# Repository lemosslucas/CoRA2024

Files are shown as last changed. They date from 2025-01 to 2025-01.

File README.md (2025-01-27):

# CoRA 2024 (Competição de Robôs Autônomos) - Line Follower

CoRA2024 Banner

This is a repository containing all the files utilised on the development and tests of our autonomous line follower robot.
The competition challenge participants to prototype, build, program and test the robot from scratch, with the help of tools such as Arduino (and languages alike), and CAD and Simulation softwares.

## File Structure
- `data/`: All the relevant data acquired during testing and programs to do so
- `miscellaneous`: All the files regarding the building of the robot and circuitry
- `CoRA2024.ino`: Main file in Arduino to compile/run the code and test the robot
- `motores.cpp`: Specific script to implement the motorised functions of the robot
- `motores.h`: Library referring to `motores.cpp` and its functions
- `desafios.cpp`: Specific scripts to tackle the track's challenges with the robot 
- `desafios.h`: Library referring to `desafios.cpp` and its functions

## Technologies used
### Programming Languages
- [Arduino / C++](https://www.arduino.cc/): Main Framework
- [C](https://learn.microsoft.com/pt-br/cpp/c-language/): Libraries and other implementations
- [Python](https://python.org): Data Analysis
- [MATLAB](https://www.mathworks.com/products/matlab.html): Data Plotting and Analysis

### Hardware
<a href="miscellaneous/CoRA2024_ElectronicCircuit.png">
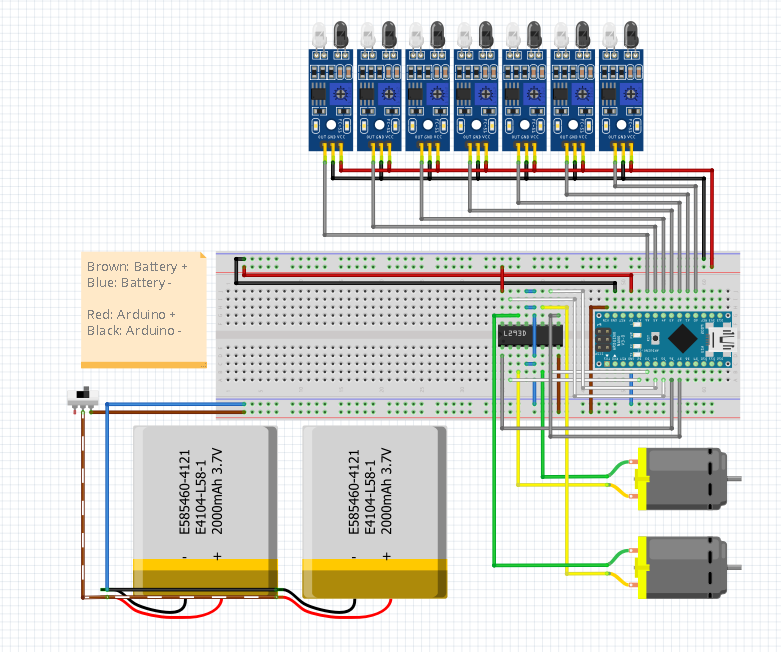
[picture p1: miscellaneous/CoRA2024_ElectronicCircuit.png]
Electronic Circuit
  
</a>
<p><b>This is a schematic of the electronic circuitry used.</b></p>

- [2x Yellow DC Motors](https://i0.wp.com/myduino.com/wp-content/uploads/2023/09/2-40.jpg?w=600&ssl=1) - **Specs:** 3V-12VDC; 1:48 gear ratio; 800g/cm max. @ 3VDC; 70mA (250mA max. @ 3VDC)
- [2x Yellow DC Motor Wheels](https://kitsguru.com/cdn/shop/products/tracked-wheel-for-bo-motor-yellow-26mm-width_2048x.jpg?v=1642829900)
- [1x Swivel Caster Wheel](https://www.institutodigital.com.br/wp-content/uploads/2020/10/rodizio-giratorio-25mm-2.png)
- [2x 18650 Lithium-ion battery cells](https://electrostoreshop.com/wp-content/uploads/2024/04/3-7v-2000mah-18650-rechargeable-li-ion-lithium-battery.jpg) - **Specs:** 3.7VDC; 2000mAh
- [1x Arduino Nano](https://store.arduino.cc/products/arduino-nano)
- [1x Breadboard and Jumper Cables](https://images.squarespace-cdn.com/content/v1/556646a4e4b0bda793faf918/1595041751201-D74U6ZYRW93A6ZW6YYMK/BRBRD830J+Breadboard+MB102+w.+65+Jumper+cables.jpg)
- [1x L293D CI Motor Driver](https://www.ti.com/lit/ds/symlink/l293.pdf?HQS=dis-mous-null-mousermode-dsf-pf-null-wwe&ts=1723753701665)
- [7x TCRT5000 Infrared Sensors](https://www.haoyuelectronics.com/Attachment/TCRT5000/tcrt5000.pdf)

## Media and Miscellaneous
<a href="https://www.youtube.com/watch?v=5h6ZvlgcDps">
  Participation in the Autonomous Robot Competition at UFMG (CoRA) 2024
</a>
<p>This video showcases our participation in the Autonomous Robot Competition at UFMG (CoRA) 2024, and our performance in the Final round.</p>

<a href="miscellaneous/CoRA2024_LaserCutChassis.png">
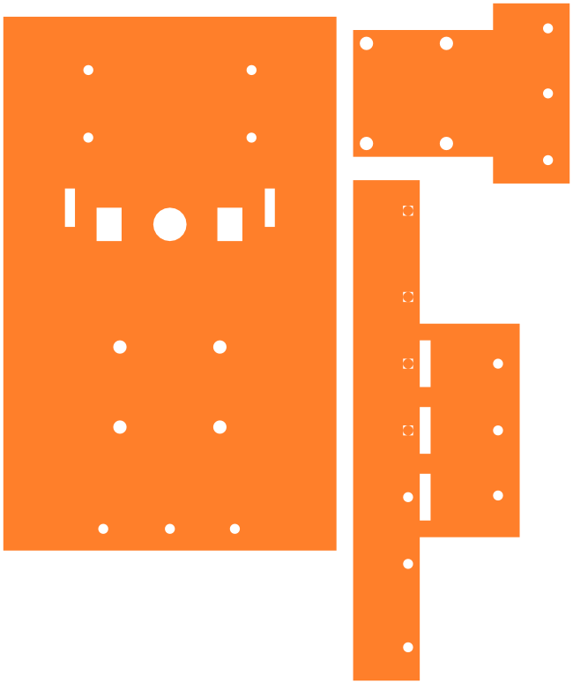
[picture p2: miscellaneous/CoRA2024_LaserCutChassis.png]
Laser Cut Chassis
  
</a>
<p>This is the vector of the chassis used to assemble the parts on, and thus the whole robot.</p>

<a href="miscellaneous/CoRA2024_SharkFrame3DPrinting.png">
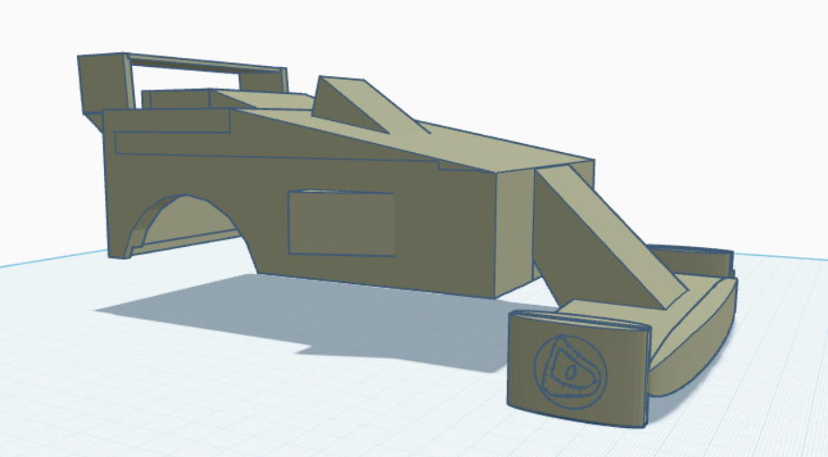
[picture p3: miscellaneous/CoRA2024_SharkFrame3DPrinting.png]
Shark Frame 3D Printing
  
</a>
<p>This is the representation of our decorative frame for the robot.</p>

## Developers

<table>
  <tr>
    <td align="center" style="max-width: 200px;">
      <a href="https://github.com/lemosslucas" target="_blank">
        
      </a>
      <br/>
      <a href="https://github.com/lemosslucas"><strong>Lucas Lemos Ricaldoni</strong></a><br/>
      <span>Lead Programmer, Principal Technician</span>
    </td>
    <td align="center" style="max-width: 200px;">
      <a href="https://github.com/mateusdcp13"> 
        
      </a>
      <br/>
      <a href="https://github.com/mateusdcp13"><strong>Mateus de Carvalho Pedrosa</strong></a><br/>
      <span>Lead Prototyper and Technician</span>
    </td>
    <td align="center" style="max-width: 200px;">
      <a href="https://github.com/PauloMendesPVRM"> 
        
      </a>
      <br/>
      <a href="https://github.com/PauloMendesPVRM"><strong>Paulo Vasconcelos Mendes</strong></a><br/>
      <span>Lead Designer and Support Prototyper</span>
    </td>
  </tr>
</table>

### Name of the team: "Pregadores"

## License
This project is licensed under the MIT License. See the file [LICENSE](LICENSE) for details.

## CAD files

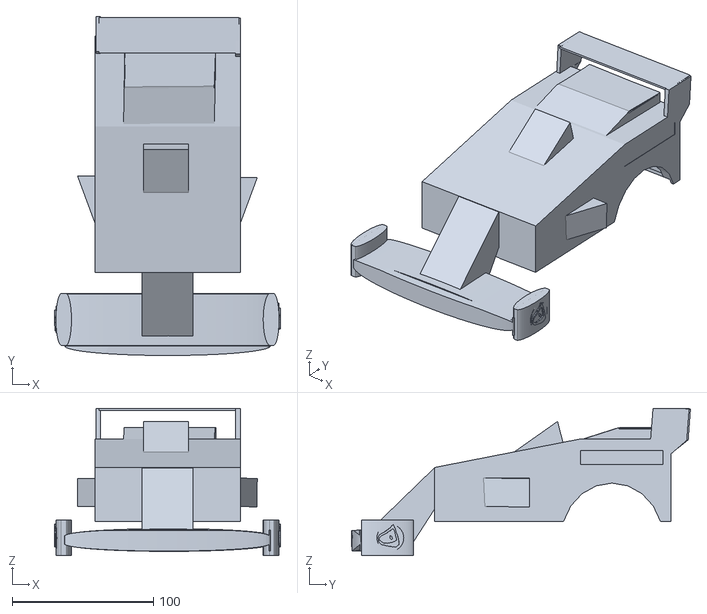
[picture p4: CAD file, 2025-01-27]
miscellaneous/CoRA2024_SharkFrame3DPrinting.stl
160.0 x 240.0 x 104.3

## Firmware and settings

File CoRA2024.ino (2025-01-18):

#include "motores.h"
#include "desafios.h"

// define os sensores
// sensor1_A1 == ESQUERDA :: sensor5_A5 == DIREITA // sensor0_curva_A0 == ESQUERDA & sensor6_curva_A6 == DIREITA
const int sensor1_A1 = 15;
const int sensor2_A2 = 16;
const int sensor3_A3 = 17;
const int sensor4_A4 = 18;
const int sensor5_A5 = 19;

//sensores para a curva
const int sensor0_curva_A0 = 14;
const int sensor6_curva_A6 = 10;

// variaveis para ler a saida do sensor
int SENSOR[5];
int SENSOR_CURVA[2];

#define BRANCO 0
#define PRETO 1
#define OFFSET 0
#define LINHA_NAO_DETECTADA -5
#define QUANTIDADE_TOTAL_SENSORES 5
#define CURVA_NAO_ENCONTRADA 0

#define DETECCAO_POR_QUADRADO 1
#define SAIDA_ESQUERDA 0
#define SAIDA_DIREITA 1
int saida_rotatoria = -1;

const int velocidadeBaseDireita = 160; 
const int velocidadeBaseEsquerda = 180; 
int velocidadeDireita = 0;
int velocidadeEsquerda = 0;

// variaveis para o calculo do PID
float erro = 0;
float erroAnterior = 0;
float I = 0, P = erro, D = 0, PID = 0;

//Constante para a utilizacao do metodo Ultimate Gain
const float Kcr = 150, Pcr = 0.05;

//parece que o melhor Kp é [150]
//const float Kp = 150, Ki = 0, Kd = 0;
const float Kp = (0.6 * Kcr), Ki = ((2 * Kp) / Pcr), Kd = ((Kp * Pcr) / 8);

// variavel para deteccao da faixa de pedestre
bool faixa_de_pedestre = false;

void setup() {
  // inicializacao dos sensores
  pinMode(sensor1_A1, INPUT);
  pinMode(sensor2_A2, INPUT);
  pinMode(sensor3_A3, INPUT);
  pinMode(sensor4_A4, INPUT);
  pinMode(sensor5_A5, INPUT);
  pinMode(sensor0_curva_A0, INPUT);
  pinMode(sensor6_curva_A6, INPUT);

  // garante que o carro começe parado
  parar();
  delay(2000);

  // inicializa a comunicacao serial
  Serial.begin(9600);
}

/**
 * @brief Le os estados [0, 1] detectados pelo sensor.
 * 
 * Atualiza os arrays SENSOR & SENSOR_CURVA com os valores
 * atuais detectados pelo sensor
 */
void ler_sensores() {
  SENSOR[0] = digitalRead(sensor1_A1);
  SENSOR[1] = digitalRead(sensor2_A2);
  SENSOR[2] = digitalRead(sensor3_A3);
  SENSOR[3] = digitalRead(sensor4_A4);
  SENSOR[4] = digitalRead(sensor5_A5);

  SENSOR_CURVA[0] = digitalRead(sensor0_curva_A0);
  SENSOR_CURVA[1] = digitalRead(sensor6_curva_A6);
}

/**
 * @brief Ajusta o movimento do carro
 * 
 * Apartir do valor gerado pelo PID junto com a velocidade base dos motores
 * altera a direção do movimento para permanecer na linha
 */
void ajusta_movimento() {
  // altera o valor de velocidade
  velocidadeDireita = constrain(velocidadeBaseDireita - PID, 0, 255);
  velocidadeEsquerda = constrain(velocidadeBaseEsquerda + PID, 0, 255);
  
  // envia a nova velocidade para a função andar
  andar(velocidadeDireita, velocidadeEsquerda);
}

/**
 * @brief Calcula o erro do carro em relação a linha
 * 
 * Realiza uma media ponderada com os valores do sensor
 * gerando o erro do carro em relacao a linha.
 */
void calcula_erro() {
  // atualiza os valores do sensor
  ler_sensores();

  // verifica se houve inversao, sinalizando uma faixa de pedestre
  if (verifica_inversao(SENSOR, SENSOR_CURVA)) {
    faixa_de_pedestre = true;
  }

  // inicializa as variaveis para o calculo do erro
  int pesos[5] = {-2, -1, 0, 1, 2};
  int somatorioErro = 0;
  int sensoresAtivos = 0;

  // realiza um somatorio com os valores e o peso dos sensores
  for (int i = 0; i < 5; i++) {
    somatorioErro += SENSOR[i] * pesos[i];
    sensoresAtivos += SENSOR[i];
  }

  // determina o erro do carro
  if (sensoresAtivos == QUANTIDADE_TOTAL_SENSORES) {
    erro = LINHA_NAO_DETECTADA;
  } else {
    int sensoresInativos = QUANTIDADE_TOTAL_SENSORES - sensoresAtivos;
    erro = somatorioErro / sensoresInativos;
  }
}

/**
 * @brief Realiza o calculo do PID
 * 
 * A partir do erro e os valores das constantes,
 * Kp, Ki e Kd predefinidas realiza o calculo do
 * Controle Proporcional Derivativo (PID)
 */
void calcula_PID() {
  // inicializa as variaveis para o calculo
  PID = 0;
  P = erro;
  I = constrain(I + P, -255, 255);
  D = erro - erroAnterior;

  // calcula o PID
  PID = (Kp * P) + (Ki * I) + (Kd * D) + OFFSET;

  // atualiza o valor do PID
  erroAnterior = erro;
}

/**
 * @brief Imprime os dados do carro no monitor serial
 * 
 * Imprime os valores lido, PID, erro e a velocidade do carro
 */
void imprime_serial() {
  // imprime os valores do sensores
  Serial.print(SENSOR_CURVA[0]);
  Serial.print(" | ");

  for (int i = 0; i < 5; i++) {
    Serial.print(SENSOR[i]);
    Serial.print(" | ");
  }

  Serial.print(SENSOR_CURVA[1]);
  Serial.print(" | ");

  // imprime as variaveis Erro, PID, e velocidades
  Serial.print("\tErro: ");
  Serial.print(erro);
  Serial.print(" PID: ");
  Serial.print(PID);
  Serial.print(" Velocidade Direita: ");
  Serial.print(velocidadeDireita);
  Serial.print(" Velocidade Esquerda: ");
  Serial.println(velocidadeEsquerda);
}

/**
 * @brief Determina o lado da saída em uma rotatória baseado no número de marcações detectadas.
 * 
 * @param marcacoesEsquerda Armazena as marcacoes a esquerda
 * @param marcacoesDireita Armazena as marcacoes a direita
 * 
 * A partir do numero de marcações a função atualiza o lado correto para
 * a saida do carro na rotatoria.
 * 
 * @return int saidaDesejada 
 */
int determina_saida_rotatoria(int marcacoesEsquerda, int marcacoesDireita) {
  // inicializa com 0 a variavel
  int saidaDesejada = 0;

  // verifica qual lado deve ser feito a saida
  if (marcacoesEsquerda > marcacoesDireita) {
    // calcula a saida apartir do numero de marcacaoes por detecacao no intervalo de tempo + OFFSET(1)
    saidaDesejada = (marcacoesEsquerda / DETECCAO_POR_QUADRADO) + 1;
    // realiza o movimento para entrar na rotatoria
    curva_esquerda(velocidadeBaseDireita, velocidadeBaseEsquerda);
    // atualiza o valor da saida
    saida_rotatoria = SAIDA_ESQUERDA;
  } else if(marcacoesEsquerda < marcacoesDireita) {
    // calcula a saida apartir do numero de marcacaoes por detecacao no intervalo de tempo + OFFSET(1)
    saidaDesejada = (marcacoesDireita / DETECCAO_POR_QUADRADO) + 1; 
    // realiza o movimento para entrar na rotatoria
    curva_direita(velocidadeBaseDireita, velocidadeBaseEsquerda);
    // atualiza o valor da saida
    saida_rotatoria = SAIDA_DIREITA;
  }
  
  //retorna o valor de saida
  return saidaDesejada;
}

/**
 * @brief Realiza a saida na rotatoria
 * 
 * @param saidaDesejada Numero que deve ser feito a saida da rotatoria
 * 
 * O carro segue o percurso ate chegar na `saidaDesejada`
 */
void realiza_rotatoria(int saidaDesejada){
  // inicializa a saida atual
  int saidaAtual = 1;

  // loop para que o carro sai apenas na saida correta
  while(saidaAtual != saidaDesejada) {
    // calcula o erro para manter o carro na linha
    calcula_erro();
    ajusta_movimento();

    // verifica qual lado deve ser feito a saida
    if (saida_rotatoria == SAIDA_ESQUERDA) {
      // verifica se ha alguma marcacao na direita
      if (calcula_sensores_ativos(SENSOR) <= 3 && SENSOR_CURVA[0] == PRETO && SENSOR_CURVA[1] == BRANCO) {
        delay(200);
        // atualiza o valor da saida atual
        saidaAtual++;
      }
    } else if(saida_rotatoria == SAIDA_DIREITA) {
      // verifica se ha alguma marcacao na esquerda
      if (calcula_sensores_ativos(SENSOR) <= 3 && SENSOR_CURVA[0] == BRANCO && SENSOR_CURVA[1] == PRETO) {
        delay(200);
        // atualiza o valor da saida atual
        saidaAtual++;
      }
    }
  }
  
  // sai para o lado correto da rotatoria
  if (saida_rotatoria == SAIDA_ESQUERDA) {
    curva_esquerda(velocidadeBaseDireita, velocidadeBaseEsquerda);
  } else {
    curva_direita(velocidadeBaseDireita, velocidadeBaseEsquerda);
  }
}

/**
 * @brief Realiza a marcha re
 * 
 * @param int historico
 * 
 * A partir do historico o robo segue o trajeto dando marcha re e
 * ao chegar ao determinado local ele vira para o lado indicado
 */
void realiza_marcha_re(int historico[]) {
  // atualiza o valor de historico
  for (int i = 0; i < DETECCAO_POR_QUADRADO; i++) {
    if (i > 0) {
      historico[i] == historico[i - 1];
    } 
  }

  // realiza a re ate chegar no local maximo
  while (erro != LINHA_NAO_DETECTADA) {
    andar_de_re(255, 255);
    calcula_erro();
  }
  parar();
  delay(500);

  // se o primeiro for esquerda ele vira a direita
  if (historico[1] == SAIDA_ESQUERDA) {
    curva_direita(velocidadeBaseDireita, velocidadeBaseEsquerda);
  } else {
    curva_esquerda(velocidadeBaseDireita, velocidadeBaseEsquerda);
  }
}

void loop() {
  // iniciliza as variaveis
  int marcacoesDireita = 0, marcacoesEsquerda = 0;
  // calcula o erro do carro sobre a linha
  calcula_erro();

  // verifica se ha uma curva de 90
  int saidaCurva = verifica_curva_90(SENSOR, SENSOR_CURVA);
  int historico_curva[4 * DETECCAO_POR_QUADRADO];
  int i = 0;

  // verifica se a curva foi detectada
  if (saidaCurva != CURVA_NAO_ENCONTRADA) { 
    // caso tenha curva armazena a quantidade de marcaçoes
    while(erro != LINHA_NAO_DETECTADA) {
      // atualiza o valor dos sensores
      ler_sensores();
      
      // atualiza os valores de identificacao
      if (SENSOR_CURVA[0] == BRANCO) {
        marcacoesEsquerda++;
        historico_curva[i] = SAIDA_ESQUERDA;
      } else if (SENSOR_CURVA[1] == BRANCO) {
        marcacoesDireita++;
        historico_curva[i] = SAIDA_DIREITA;
      }

      i++;
      // garantem que o robo continue na linha
      calcula_erro();
      calcula_PID();
      ajusta_movimento();
    }
    
    // determina qual acao deve ser feita
    if (marcacoesEsquerda == DETECCAO_POR_QUADRADO || marcacoesDireita == DETECCAO_POR_QUADRADO) {
      realiza_curva_90(saidaCurva);
    } else if ((marcacoesEsquerda / DETECCAO_POR_QUADRADO) > 1 && (marcacoesDireita / DETECCAO_POR_QUADRADO) > 1) {
      realiza_marcha_re(historico_curva);
    } else{
      determina_saida_rotatoria(marcacoesEsquerda, marcacoesDireita);
    }

    parar();
  } else {
    // caso nao detectado curva e tenha perdido a linha
    if (erro == LINHA_NAO_DETECTADA) {
      // atualiza o numero de sensores ativos
      int sensoresAtivos = calcula_sensores_ativos(SENSOR);
      PID = 0;
      parar();

      // verifica se é uma faixa de pedestre
      if (faixa_de_pedestre == true) {
        realiza_faixa_de_pedestre();
        faixa_de_pedestre = false;
      } else {  
        delay(10000);

        // realiza uma re ate que volte para a linha
        while(sensoresAtivos == QUANTIDADE_TOTAL_SENSORES) {
          ler_sensores();
          sensoresAtivos = calcula_sensores_ativos(SENSOR);
          andar_de_re(255, 255);
        }

        parar();
      }

    } else {
      // caso o carro detecte a linha ele segue a linha
      calcula_PID();
      ajusta_movimento();
    }
  }

  // obtem a saida dos dados do carro
  imprime_serial(); 
  delay(5);
}

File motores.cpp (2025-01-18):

#include "motores.h"

// define a porta dos motores
const int MOTOR_ESQUERDO_HORARIO = 3;
const int MOTOR_ESQUERDO_ANTI = 4;
const int MOTOR_DIREITO_HORARIO = 7;
const int MOTOR_DIREITO_ANTI = 8;

const int MOTOR_PWM_ESQUERDO = 5;
const int MOTOR_PWM_DIREITO = 6;

void setup_motor() {
  pinMode(MOTOR_ESQUERDO_HORARIO, OUTPUT);
  pinMode(MOTOR_ESQUERDO_ANTI, OUTPUT);
  pinMode(MOTOR_DIREITO_HORARIO, OUTPUT);
  pinMode(MOTOR_DIREITO_ANTI, OUTPUT);

  pinMode(MOTOR_PWM_ESQUERDO, OUTPUT);
  pinMode(MOTOR_PWM_DIREITO, OUTPUT);
}

/**
 * @brief Move o veiculo para frente com as velocidades especificadas.
 * 
 * Configura os motores para se moverem para frente e ajusta suas velocidades
 * individualmente usando PWM.
 * 
 * @param velocidadeDireita Velocidade do motor direito (0 a 255).
 * @param velocidadeEsquerda Velocidade do motor esquerdo (0 a 255).
 */
void andar(int velocidadeDireita, int velocidadeEsquerda) {
  digitalWrite(MOTOR_ESQUERDO_ANTI, LOW);
  digitalWrite(MOTOR_ESQUERDO_HORARIO, HIGH);
  digitalWrite(MOTOR_DIREITO_HORARIO, HIGH);
  digitalWrite(MOTOR_DIREITO_ANTI, LOW);

  analogWrite(MOTOR_PWM_ESQUERDO, velocidadeEsquerda);
  analogWrite(MOTOR_PWM_DIREITO, velocidadeDireita);
}

/**
 * @brief Para todos os motores, interrompendo o movimento do veiculo.
 */
void parar() {
  digitalWrite(MOTOR_ESQUERDO_ANTI, LOW);
  digitalWrite(MOTOR_ESQUERDO_HORARIO, LOW);
  digitalWrite(MOTOR_DIREITO_HORARIO, LOW);
  digitalWrite(MOTOR_DIREITO_ANTI, LOW);
}

/**
 * @brief Move o veiculo para tras com as velocidades especificadas.
 * 
 * Configura os motores para se moverem para tras e ajusta suas velocidades
 * individualmente usando PWM.
 * 
 * @param velocidadeDireita Velocidade do motor direito (0 a 255).
 * @param velocidadeEsquerda Velocidade do motor esquerdo (0 a 255).
 */
void andar_de_re(int velocidadeDireita, int velocidadeEsquerda) {
  digitalWrite(MOTOR_ESQUERDO_ANTI, HIGH);
  digitalWrite(MOTOR_ESQUERDO_HORARIO, LOW);
  digitalWrite(MOTOR_DIREITO_HORARIO, LOW);
  digitalWrite(MOTOR_DIREITO_ANTI, HIGH);

  analogWrite(MOTOR_PWM_ESQUERDO, velocidadeEsquerda);
  analogWrite(MOTOR_PWM_DIREITO, velocidadeDireita);
}

/**
 * @brief Executa uma curva de 90 graus para a direita.
 * 
 * Configura os motores para girar de modo a realizar uma curva para a direita.
 * A funcao ajusta a velocidade do motor esquerdo e usa um `delay` para controlar
 * o tempo da curva.
 * 
 * @param velocidadeDireita Velocidade do motor direito (0 a 255).
 * @param velocidadeEsquerda Velocidade do motor esquerdo (0 a 255).
 * 
 * @note O `delay(600)` determina a duracao da curva; ajuste conforme necessario.
 */
void curva_direita(int velocidadeDireita, int velocidadeEsquerda) {
  digitalWrite(MOTOR_ESQUERDO_ANTI, HIGH);
  digitalWrite(MOTOR_ESQUERDO_HORARIO, LOW);
  digitalWrite(MOTOR_DIREITO_HORARIO, HIGH);
  digitalWrite(MOTOR_DIREITO_ANTI, LOW);
  
  analogWrite(MOTOR_PWM_ESQUERDO, velocidadeEsquerda + 40);
  analogWrite(MOTOR_PWM_DIREITO, velocidadeDireita);
  delay(600);
}

/**
 * @brief Executa uma curva de 90 graus para a esquerda.
 * 
 * Configura os motores para girar de modo a realizar uma curva para a esquerda.
 * A funcao ajusta a velocidade do motor direito e usa um `delay` para controlar
 * o tempo da curva.
 * 
 * @param velocidadeDireita Velocidade do motor direito (0 a 255).
 * @param velocidadeEsquerda Velocidade do motor esquerdo (0 a 255).
 * 
 * @note O `delay(600)` determina a duracao da curva; ajuste conforme necessario.
 */
void curva_esquerda(int velocidadeDireita, int velocidadeEsquerda) {
  digitalWrite(MOTOR_ESQUERDO_ANTI, LOW);
  digitalWrite(MOTOR_ESQUERDO_HORARIO, HIGH);
  digitalWrite(MOTOR_DIREITO_HORARIO, LOW);
  digitalWrite(MOTOR_DIREITO_ANTI, HIGH);

  analogWrite(MOTOR_PWM_ESQUERDO, velocidadeEsquerda);
  analogWrite(MOTOR_PWM_DIREITO, velocidadeDireita + 40);
  delay(600);
}

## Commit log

2024-07-16 Codigo com a logica de seguir a linha, ainda, necessario a logica da curva de 90
2024-07-26 Curva de 90 adicionada
2024-08-19 Adicao de novas funcoes
2024-08-19 Update motores.cpp
    correção de mudanças que nao foram adicionadas
2024-08-31 Adicao de funcoes para o controle PID
2024-08-31 Correcoes de eventuais bugs nas novas funcoes
2024-09-06 Atualizacao para realizacao de testes
2024-09-21 Correcao do bug no commit
    [CoRA2024.ino]
2024-09-28 Atualizacoes para teste
2024-10-05 Atualizacao para a realizacao da curva de 90
2024-10-06 Anda reto, faz curva de 90, zigue zigue, anda no tunel, e intercecao
2024-10-06 Atualizacao com a modularizacao das funções e adicionamento da funcao de pista invertida
2024-10-09 Atualizacao precisando encontrar o pid ideal
2024-10-11 Atualização para a realizacao da rotatoria e da marcha re
